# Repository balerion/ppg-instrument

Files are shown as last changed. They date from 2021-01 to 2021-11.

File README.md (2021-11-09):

# ppg-instrument
This is an instrument meant for assisting in the monitoring of combustion engines in powered paragliding.

The main features are an RPM gauge, temperature sensors, and hour meter.

There are plans for including and logging other sensors, such as accelerometers, barometer, temperature/humidity.

There are also plans for including a customizable maintenance schedule.

## Electronics
This is based on the [Adalogger](https://www.adafruit.com/?q=adalogger&sort=BestMatch) (trying to support both 32u4 and M0), because of the nice format and space savings from having battery management and SD on the board.

The display is a 0.91" OLED, the choice is mainly due to what I had lying around. A nice drop-in alternative can be a 0.96" OLED, this will probably come in the future.

RPM readings are performed by capacitive coupling a pigtail wire to the spark plug cable. There is a board I designed with input protection for the uController pins.

I wanted to avoid hard switches due to vibrations, in case the instrument gets mounted on the swing arms, so I ended up using all software-based power management and steel tactile domes.

Temperature readings are performed with K-type thermocouples and an AD8495 based amplifier, such as the relatively cheap CJMCU 8495 boards

### Note on thermocouple sensor
The thermocouple CHT (cylinder head temperature) sensor is kind of tricky. This is an insulated thermocouple connected to a spark plug gasket.

The sensors you can find online are really expensive or do not work well. Since electrical insulation is needed due to large voltage oscillations of the engine block, commercial cheaper sensors tend to use ceramics just dropped in a steel tube, and have a huge air gap between the thermocouple junction and the spark plug gasket. Furthermore, the gaskets are usually made of steel. This makes the response extremely slow: dipped in boiling water, it takes 10 minutes to get 95°C.

A CHT sensor can easily be built using an M12 eye cable lug, which needs to be adapted to remove the tinning, smooth out the surface, and make the hole 14.2mm.

After adapting the gasket, the thermocouple junction can be insulated using a wrap of kapton tape (max T>300C), then tightly wrapping in aluminum foil, and then carefully crimping the thermocouple junction in the eye terminal.

## Case
For the case, there are 2 parts plus the buttons that can be 3d printed with an FDM printer.

I printed all parts in PLA with 0.2mm layers, the lid and box with supports. For printing the buttons, make sure the first layer height is just right.

Inspiration for the buttons came from [here](https://www.instagram.com/p/BypbXyjohMr/)

I also use a 1" dual hook & loop strap (like velcro omni-tape) to keep it fixed to my throttle.

## Assembly Instructions
Check [here](hardware/Assembly%20Instructions/Instructions.md) for assembly instructions.

### Parts List 
|Part|Source|Price| 
| --- |:---:| -----:|
| Adalogger board | [Adafruit](https://www.adafruit.com/product/2796), [Amazon](https://www.amazon.de/Adafruit-Feather-M0-Adalogger-ADA2796/dp/B01BMRDBXW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) | €27.90 |
| Battery | [1300mAh 503759](https://www.ebay.com/itm/171260143191) | €6.60 |
| SD card | [ebay, 4Gb](https://www.ebay.it/itm/303426113204?ssPageName=STRK%3AMEBIDX%3AIT&_trksid=p2060353.m2749.l2649) | €7.16 |
| Thermocouple amp | [Aliexpress](https://www.aliexpress.com/i/33014907258.html) | $5.38 |
| Thermocouple wire | [ebay](https://www.ebay.it/itm/274905710453?hash=item4001a83f75:g:jTAAAOSwh59hFzC6) | €2.48 per meter |
| Spark plug gasket | [Amazon](https://www.ebay.it/itm/272789432218?hash=item3f8384679a:g:DPAAAOSwQcJaDBZB) | ~ €2.00 per piece |
| 3D printed parts | filament | ~ €1.00 |
| Spark plug input board | | ~ €3.00 |
| Screen | [0.91" white oled, Amazon](https://www.amazon.de/-/en/0-91-I2-°C-Serial-128x32-White-Display-Arduino/dp/B06XFHGT9P/ref=sr_1_3?keywords=0%2C91+weiß+oled&qid=1636468399&qsid=262-1393502-5513624&sr=8-3&sres=B07V8B3LSR%2CB07TKPXFLV%2CB06XFHGT9P%2CB0979YQWGT%2CB08K8XVJBT%2CB07TWJR7L9%2CB07JN2NHT4%2CB079KRC9X3%2CB01IROOJ48%2CB08216LXVQ%2CB01N97V0KH%2CB07FYG8MZN%2CB074N9VLZX%2CB014I8SIJY%2CB07PGZ9B51%2CB08MZV1TT9) | €3.00 per piece |
| hook&loop strap | [treadlite](https://www.treadlitegear.co.uk/ripfast-solo-hook-and-loop-in-20mm-and-25mm-hiking-bike-packing-choose-length-211-p.asp)  | £5.99 |
| Tactile dome switches | [Aliexpress](https://www.aliexpress.com/item/32668884101.html) | $0.24 for 2 pieces |

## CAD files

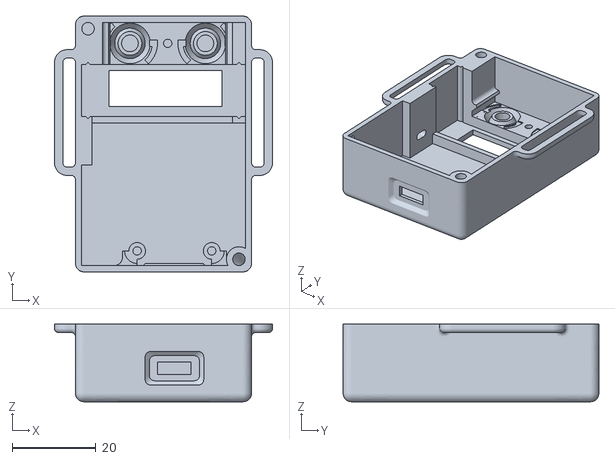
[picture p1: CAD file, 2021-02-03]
hardware/ppg-instrument box_v1.0.stl
52.0 x 61.0 x 18.5

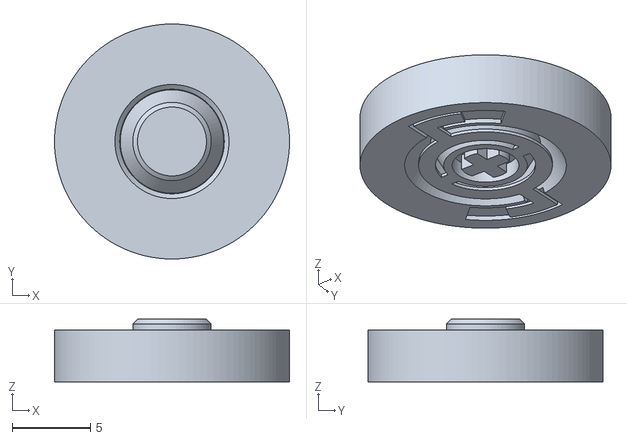
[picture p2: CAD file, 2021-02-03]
hardware/button_small.stl
15.0 x 15.0 x 4.00

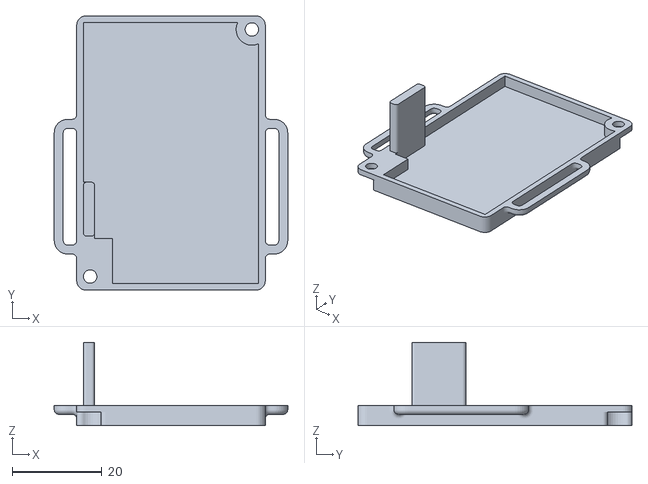
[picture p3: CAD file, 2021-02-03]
hardware/lid_v1.0.stl
52.0 x 61.0 x 18.5

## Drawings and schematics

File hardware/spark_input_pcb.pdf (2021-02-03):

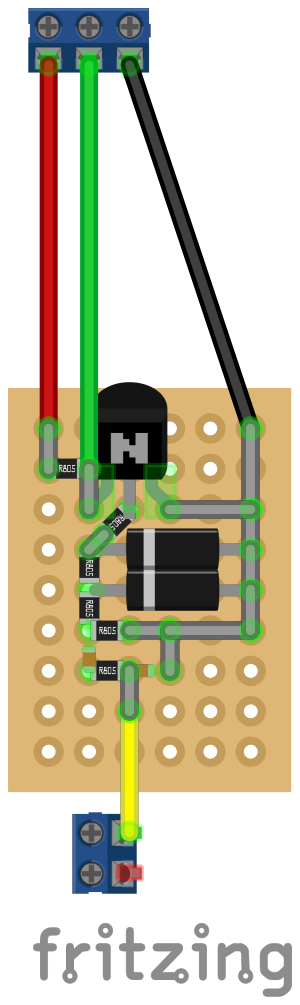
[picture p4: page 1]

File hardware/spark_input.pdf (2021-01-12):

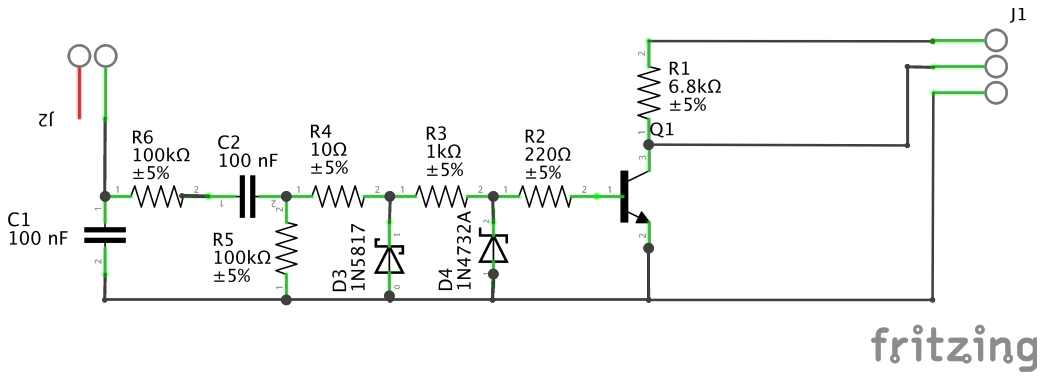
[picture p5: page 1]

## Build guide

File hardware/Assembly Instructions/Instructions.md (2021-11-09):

# Assembly

To start the assembly, you will most likely need:

- The instrument case
- The main board (Feather M0/32u)
- Buttons board
- Thermocouple board
- Spark plug sensor board
- Battery
- Screen

There really isn't so much space in the case, so I made these instructions to show how I assembled the instrument.

# Buttons
For the buttons, I chose to go for a cheaper, more reliable, more customizable way. This is however a little more tricky.
You need some of [these](https://www.aliexpress.com/item/32668884101.html).

You can use 2x steel tactile dome switches (triangular 6mm, 2 leg such as ), and a pcb. A piece of perfboard should also work.

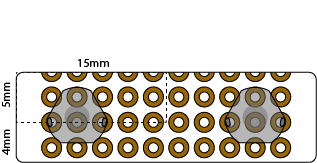
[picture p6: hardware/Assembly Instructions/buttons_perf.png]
image of perf buttons


The board size is 30mm x 9mm, with buttons distanced 18mm and centered on the board. If you are using perfboard, the switch leg holes will not be centered vertically, but will be 5mm/4mm away from the top and bottom edge.

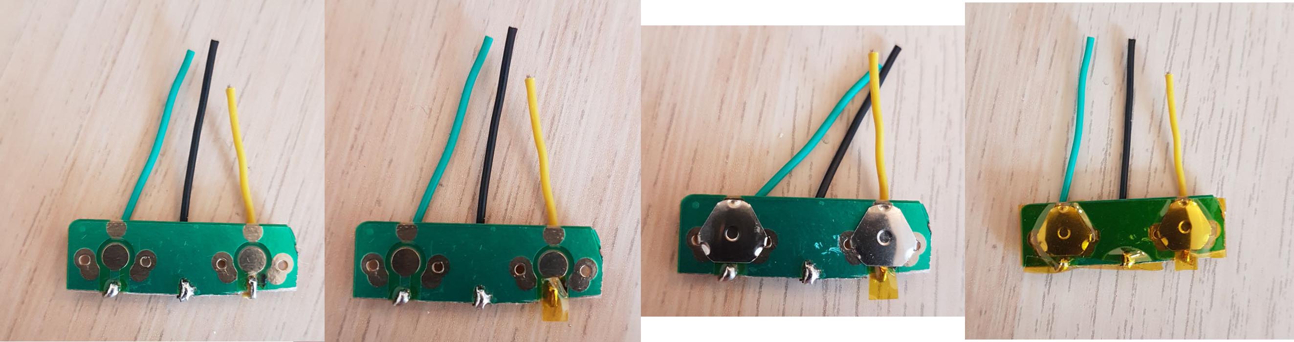
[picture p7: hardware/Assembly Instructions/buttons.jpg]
button assembly


Isolate the connections coming from the central pad with PCB enamel or a little bit of kapton tape, otherwise the buttons will be shorted all the time.

Connect very thin wires to close-by pads, use very little solder so the connection is as thin as possible and fits under the button. Use a solder wick to help out getting a thin layer.
Then, from such near-by pads, get thicker wires to go to the back of the board.

The dome switch feet need to be grounded, while the central pad goes to the input pin.

Covering the buttons with tape helps keep them in place.

In the end, you get one wire per button plus the ground.

# Spark plug sensor
The spark plug input circuit works by capacitive coupling a pigtail wire to the spark plug cable. The spark plug cable itself will reach pretty high negative voltages, in the 10kV range. This in turn causes a positive voltage spike in the pigtail wire. The circuit is designed with an input low pass filter, so the spike does not reach dangerous values, and right after this, a high pass filter that is more meant as a protection than a filter. Then, there are two diodes for input protection against overvoltages and undervoltages for a transistor, which generates a ~20us low-logic pulse every time a spark happens.

In general, 5-6 wraps should be sufficient. Use the smallest number of wraps that will give a consistent reading. Too many wraps can cause issues with ignition and may damage the board.

spark plug sensor schematic

You can make the circuit on perf board, using smd components.

Remember to wrap the whole sensor in isolating tape, it is probably not a good idea to have shorts with other parts of the instrument.

# Fitting all the parts

Start by placing the 3d printed butting in their niches. Then, insert the button board in the retaining shelf. this is a pretty tight fit, so be patient and get it to align well.

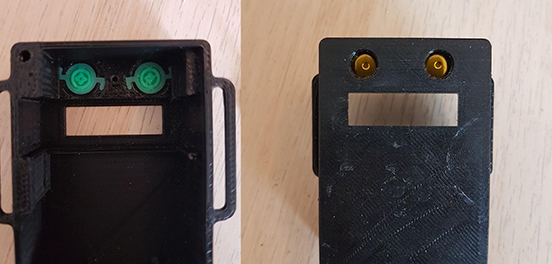
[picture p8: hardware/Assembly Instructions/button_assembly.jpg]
fitting buttons


The screen is small and quite delicate. Be careful when assembling. Should probably design a better retaining niche.

The micro SD card quality is quite important. When not in use, larger, faster SD cards will use up a lot of battery. Try to find cheap, slow ones. [These](https://www.ebay.it/itm/303426113204?ssPageName=STRK%3AMEBIDX%3AIT&_trksid=p2060353.m2749.l2649) 4Gb cards use 200uA when in standby.

Isolate the SD card slot with some tape. This can cause shorts with the underlying boards.

After this, try fitting the feather board. This will give you a good idea of where the connection wires should be. Try to keep this arrangement while soldering all the connections.

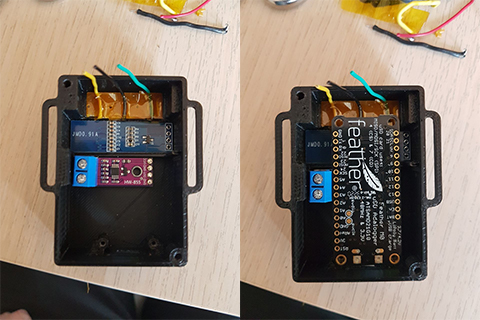
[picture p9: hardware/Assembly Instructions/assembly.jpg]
fitting feather


The battery I had lying around was a 1000mAh 60x40mmx5mm battery (504060 battery format). This was pretty old, now you can either find the same capacity with a smaller size, or up to 1800mAh for the same format. Probably a smaller battery will fit nicely.

The fastening strap is mixed hook&loop, which means it sticks to itself. I found this pretty convenient, and pretty safe.

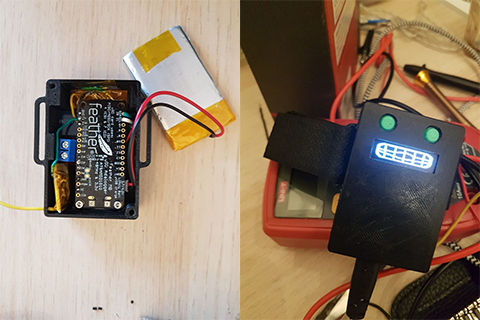
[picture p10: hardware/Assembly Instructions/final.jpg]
functioning


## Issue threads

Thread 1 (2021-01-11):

RPM meter

balerion, 2021-01-11:
The instrument needs an RPM meter

<!-- Edit the body of your new issue then click the ✓ "Create Issue" button in the top right of the editor. The first line will be the issue title. Assignees and Labels follow after a blank line. Leave an empty line before beginning the body of the issue. -->

Closed 2021-01-11.

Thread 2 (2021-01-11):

Logger

balerion, 2021-01-11:
The instrument needs to log data, most importantly operational hours.
This needs to be associated to some type of output, e.g. per flight and per service interval.

<!-- Edit the body of your new issue then click the ✓ "Create Issue" button in the top right of the editor. The first line will be the issue title. Assignees and Labels follow after a blank line. Leave an empty line before beginning the body of the issue. -->

balerion, 2021-01-12:
this can store all the info to the sd card every time interval in a dedicated folder structure

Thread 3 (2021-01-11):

Output display

balerion, 2021-01-11:
The instrument needs a meaningful output display. This can be a 0.91" OLED or a 0.96" OLED based on the SSD1306 chip.

<!-- Edit the body of your new issue then click the ✓ "Create Issue" button in the top right of the editor. The first line will be the issue title. Assignees and Labels follow after a blank line. Leave an empty line before beginning the body of the issue. -->

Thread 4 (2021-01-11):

CHT gauge

balerion, 2021-01-11:
The instrument needs thermocouple temperature readings for the CHT (and possibly for the EGT).

<!-- Edit the body of your new issue then click the ✓ "Create Issue" button in the top right of the editor. The first line will be the issue title. Assignees and Labels follow after a blank line. Leave an empty line before beginning the body of the issue. -->

Closed 2021-02-09.

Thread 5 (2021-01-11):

Sensor logging

balerion, 2021-01-11:
The instrument could log various sensors, like temperature/humidity, barometer/altimeter, accelerometers.

<!-- Edit the body of your new issue then click the ✓ "Create Issue" button in the top right of the editor. The first line will be the issue title. Assignees and Labels follow after a blank line. Leave an empty line before beginning the body of the issue. -->

balerion, 2021-01-12:
Also battery management

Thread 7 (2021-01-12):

Sleep-wakeup

balerion, 2021-01-12:
Needs a convenient software sleep/wakeup system, so no hardware battery switch is necessary.
It could use something like an interrupt (there should be one interrupt pin still free) or a check every second or so:
```
LowPower.deepSleep(milliseconds);
```

<!-- Edit the body of your new issue then click the ✓ "Create Issue" button in the top right of the editor. The first line will be the issue title. Assignees and Labels follow after a blank line. Leave an empty line before beginning the body of the issue. -->

Closed 2021-01-14.

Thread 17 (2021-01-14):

Optimize code
Assignees: @balerion
Labels: enhancement

balerion, 2021-01-14:
Needs code optimization for reducing flash space as much as possible.
Need to move the sleep/wakeup outside the loop

<!-- Edit the body of your new issue then click the ✓ "Create Issue" button in the top right of the editor. The first line will be the issue title. Assignees and Labels follow after a blank line. Leave an empty line before beginning the body of the issue. -->

balerion, 2021-02-09:
workaround is to use board with more flash. Will be moving to Adalogger M0 anyway

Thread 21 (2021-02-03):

instrument uses power even in off mode

balerion, 2021-02-03:
because sensors are connected directly to power pins, they are powered even in off state.
Possible solution is to use a digital pin to power the sensors

<!-- Edit the body of your new issue then click the ✓ "Create Issue" button in the top right of the editor. The first line will be the issue title. Assignees and Labels follow after a blank line. Leave an empty line before beginning the body of the issue. -->

balerion, 2021-02-03:
fixed in #20

Closed 2021-02-03.

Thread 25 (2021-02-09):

power usage goes up after 1s of sleep

balerion, 2021-02-09:
fixed in M0 version. In the 32u4 version, after the first sleep cycle, the board is not put back in deep sleep mode again

balerion, 2021-03-14:
fixed by 02334bd079bea62a9c9fc354ac782ae14e71a053

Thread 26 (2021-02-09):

slow rpm inaccurate

balerion, 2021-02-09:
with the current method of counting spark firings between intervals, at low rpms, the reading is inaccurate due to a variable number of firings in a check cycle (~2 in 60ms at 2000rpm), so the error becomes 1000rpm at 2000rpm

A solution is to measure time between firings instead

balerion, 2021-03-14:
fixed by 55c965e9009cd1c129962a9e6e5bf15ba3e67741

Closed 2021-03-14.

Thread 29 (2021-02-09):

wakeup slow

balerion, 2021-02-09:
the current wakeup method is super silly, considering the button pin is on an interrupt in either board. Should change to a faster interrupt based wakeup, also allowing for less battery usage when sleeping

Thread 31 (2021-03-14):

documentation needed

balerion, 2021-03-14:
needs documentation on construction, assembly, and usage

balerion, 2021-11-09:
missing assembly instructions fixed by #35

balerion, 2021-11-09:
construction info fixed by 11948a12fe45318902e3622fe65ae1f319eafc91

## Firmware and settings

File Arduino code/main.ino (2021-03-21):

#include <SPI.h>
#include <U8g2lib.h>
#include <Wire.h>

#include "ArduinoLowPower.h"
#include "SD.h"
#include "src/graphics.h"

// Pin definition
#define VBATPIN A7
#define CHTMEASUREPIN A1
#define RPMPIN 1
#define BUTTONPIN 0
#define RPMPOWER A2
#define CHTPOWER A3

#define chipSelect 4

// uncomment this for dev mode
// #define DEVMODE 1
// #define FAKERPM 1

// SAMD serial port adaptation
#if defined(ARDUINO_SAMD_ZERO) && defined(SERIAL_PORT_USBVIRTUAL)
// Required for Serial on Zero based boards
#define Serial SERIAL_PORT_USBVIRTUAL
#endif

// Battery monitoring
const float minVoltage = 3.2;
const float maxVoltage = 4.1;
const float refVoltage = 3.3;

// defines for tacho
const float min_rpm = 2000;
const float max_rpm = 8000;

float rpm_filt = 0;
float ww = 3;  // filter weight. larger numbers -> slower filters. 40 is ..s, 1
               // is no filtering

// defines for tacho: Timer auxiliary variables
unsigned long tt = millis();
unsigned long dt = micros();
volatile unsigned long t0 = micros();
volatile unsigned long t1 = micros();
// volatile unsigned long oldtime = micros();
volatile float rev = 0;
float rpm = 0;

unsigned long fakerpm_dt = 0;
unsigned long fakerpm_tt = 0;

unsigned long lastTrigger = 0;
boolean startTimer = false;

// Defining variables for OLED display
char displayBuffer[20];
String displayString;
unsigned long lastSignalBlink;
unsigned long lastDataRotation;

float batteryVoltage = 0;
float throttle = 0;

bool wasSleeping = true;
bool awake = true;
float sleepInput = 0;

// Defining the type of display used (128x32)
U8G2_SSD1306_128X32_UNIVISION_F_HW_I2C u8g2(U8G2_R0, U8X8_PIN_NONE);

// time keeping variables
long tt_loop = 0;
long loopUpdateTime = 25;
long tt_button = 0;
long dt_button = 500;
long tt_slowdraw = 0;
long dt_slowdraw = 1000;

unsigned long tt_running = 0;
unsigned long current_runtime = 0;
unsigned long total_runtime = 0;

// SD card stuff
File logfile;

// blink out an error code
void error(uint8_t errno) {
  while (1) {
    uint8_t i;
    for (i = 0; i < errno; i++) {
      digitalWrite(LED_BUILTIN, HIGH);
      delay(100);
      digitalWrite(LED_BUILTIN, LOW);
      delay(100);
    }
    for (i = errno; i < 10; i++) {
      delay(200);
    }
  }
}

// sleepy function
void prepareSleep() {
  u8g2.setPowerSave(1);
  pinMode(RPMPOWER, INPUT);
  pinMode(CHTPOWER, INPUT);
  pinMode(13, INPUT);
  digitalWrite(RPMPOWER, LOW);
  digitalWrite(CHTPOWER, LOW);
  wasSleeping = false;
  logfile.println(total_runtime);
  logfile.flush();
  logfile.close();
  LowPower.deepSleep(1000);
}

// wakeup function
void wakeupProc() {
  u8g2.setPowerSave(0);

  u8g2.clearBuffer();
  u8g2.drawXBMP(0, 0, mouth1_width, mouth1_height, mouth1_bits);
  u8g2.sendBuffer();
  delay(2000);
  u8g2.clearBuffer();

#if defined(FAKERPM)
  pinMode(RPMPOWER, INPUT);
  digitalWrite(RPMPOWER, LOW);
#else
  pinMode(RPMPOWER, OUTPUT);
  digitalWrite(RPMPOWER, HIGH);
#endif
  pinMode(CHTPOWER, OUTPUT);
  pinMode(LED_BUILTIN, OUTPUT);
  digitalWrite(CHTPOWER, HIGH);

  char filename[17];
  strcpy(filename, "logger/HOURS.TXT");
  // for (uint8_t i = 0; i < 100; i++) {
  //   filename[10] = '0' + i / 10;
  //   filename[11] = '0' + i % 10;
  //   // create if does not exist, do not open existing, write, sync after
  //   write if (!SD.exists(filename)) {
  //     break;
  //   }
  // }
  logfile = SD.open(filename, FILE_READ);
  if (!logfile) {
#if defined(DEVMODE)
    Serial.print("Couldnt open ");
    Serial.println(filename);
#endif
    error(2);
  }

  while (logfile.available()) {
    unsigned long runtime_temp = logfile.parseInt();
    if (runtime_temp > 0) {
      total_runtime = runtime_temp;
    }
  }
#if defined(DEVMODE)
  Serial.println(total_runtime);
#endif
  logfile.close();

  logfile = SD.open(filename, FILE_WRITE);
  logfile.seek(EOF);
  if (!logfile) {
#if defined(DEVMODE)
    Serial.print("Couldnt open for write ");
    Serial.println(filename);
#endif
    error(3);
  }

  // total_runtime = EEPROMReadlong(0);
}

void setup() {
  pinMode(RPMPIN, INPUT_PULLUP);
  attachInterrupt(digitalPinToInterrupt(RPMPIN), rpm_isr, FALLING);

  pinMode(BUTTONPIN, INPUT_PULLUP);

  // initialize serial:
#if defined(DEVMODE)
  Serial.begin(115200);
  while (!Serial) delay(10);  // wait for native usb
  Serial.println("Devmode ON");
#endif

  u8g2.setBusClock(400000);
  u8g2.begin();

  if (!SD.begin(chipSelect)) {
#if defined(DEVMODE)
    Serial.println("SD init failed");
#endif
  }
  wakeupProc();
}

void loop() {
  // check sleep status
  if (digitalRead(BUTTONPIN) == LOW) {
    bool switchSleepState = true;
    // stop everything for 1s while checking button is still down
    tt_button = millis();
    do {
      if (digitalRead(BUTTONPIN) == HIGH) switchSleepState = false;
    } while (millis() - tt_button < dt_button);

    // if after 1 second button is still down, switch sleep state
    if (switchSleepState) {
      if (awake) {
        prepareSleep();
        awake = false;
      } else {
        wakeupProc();
        awake = true;
      }
    }
  }

  // waking code
  if (awake) {
#if defined(DEVMODE)
    while (Serial.available() > 0) {
      // look for the next valid integer in the incoming serial stream:
      rev = Serial.parseInt();
#if defined(FAKERPM)
      fakerpm_dt = 60000.0 / rev;
#endif
      if (Serial.read() == '\n') {
        Serial.println(rev);
        if (rev < 0) {
          total_runtime = -rev;
          Serial.print("resetting total_runtime: ");
          Serial.println(total_runtime);
        }
      }
    }

#if defined(FAKERPM)
    if (millis() - fakerpm_tt > fakerpm_dt) {
      // pinmode input detaches internal pullup, so transistor in pcb takes pin
      // to 0V however, it also detaches the interrupt for some reason
      pinMode(RPMPIN, INPUT);
      delayMicroseconds(20);
      pinMode(RPMPIN, INPUT_PULLUP);
      attachInterrupt(digitalPinToInterrupt(RPMPIN), rpm_isr, FALLING);
      fakerpm_tt = millis();
    }
#endif

    // Serial.println(rpm_filt);
#endif
    if (millis() - tt_loop > loopUpdateTime) {
      updateRunningTime();
      updateTacho();
#if !defined(FAKERPM)
      readBatteryVoltage();
      readCht();
      updateMainDisplay();
#endif
      tt_loop = millis();
    }
  } else {
    prepareSleep();
    awake = false;
  }
}

void updateRunningTime() {
  if (rpm_filt > min_rpm) {
    unsigned int dt = millis() - tt_running;
    tt_running = millis();
    current_runtime += dt;
    total_runtime += dt;
  } else {
    current_runtime = 0;
    tt_running = millis();
  }
}

void displayTime() {
  // int x = 89;
  // int y = 22;
  int x = 104;
  int y = 22;
  char buffer[10];  // make this big enough to hold the resulting string
  snprintf(
      buffer, sizeof(buffer), "%02d:%02d:%02d",
      int(current_runtime / 3600000.0),
      int(current_runtime / 60000.0) - int(current_runtime / 3600000.0) * 60,
      int(current_runtime / 1000.0) - int(current_runtime / 60000.0) * 60);

  u8g2.setFont(u8g2_font_profont10_mn);
  u8g2.drawStr(x, y, buffer);

  snprintf(buffer, sizeof(buffer), "%02d:%02d:%02d",
           int(total_runtime / 3600000.0),
           int(total_runtime / 60000.0) - int(total_runtime / 3600000.0) * 60,
           int(total_runtime / 1000.0) - int(total_runtime / 60000.0) * 60);

  u8g2.setFont(u8g2_font_profont10_mn);
  u8g2.drawStr(x, y + 8, buffer);

  // Serial.print("total runtime: ");
  // Serial.println(total_runtime);
  // buffer[10];  // make this big enough to hold the resulting string
  // snprintf(buffer, sizeof(buffer), "%02d:%02d:%02d",
  //          int(total_runtime / 3600000.0),
  //          int(total_runtime / 60000.0) - int(total_runtime / 3600000.0) *
  //          60, int(total_runtime / 1000.0) - int(total_runtime / 60000.0) *
  //          60);
  // Serial.println(buffer);

  // time to OLED
  // displayString = "";
  // for (int i = 0; i < pp.decimals; i++) {
  //   if (last < pow(10, i)) {
  //     displayString = "0" + displayString;
  //   } else {
  //     displayString = (String)last;
  //   }
  // }
  // // displayString = "." + displayString;
}

// Function to calculate and return the thermocouple reading.
float readChtVoltage() {
  float chtVoltage = 0.0;
  int total = 0;
  int extrabits = 2;

  int nn = pow(2, 2 * extrabits);
  for (int i = 0; i < 16; i++) {
    total += analogRead(CHTMEASUREPIN);
  }

  chtVoltage = (refVoltage / 1024.0) * ((float)total / 16.0);

  return chtVoltage;
}

// function for calibrating cht voltage to temperature in °C
float calibratedCht(float voltage) { return (voltage - 1.25) / 0.005; }

float chtReading = 0;
void readCht() {
  float chtVoltage = readChtVoltage();
  chtReading = calibratedCht(chtVoltage);
#if defined(DEVMODE)
  Serial.print("CHT: ");
  Serial.println(chtReading);
#endif
}

void readBatteryVoltage() {
  batteryVoltage = analogRead(VBATPIN);
  batteryVoltage *= 2;           // we divided by 2, so multiply back
  batteryVoltage *= refVoltage;  // Multiply by 3.3V, our reference voltage
  batteryVoltage /= 1024.0;      // convert to voltage

#if defined(DEVMODE)
  Serial.print("VBat: ");
  Serial.println(batteryVoltage);
#endif
}

void rpm_isr() {
  t1 = micros();
  rev++;
}

void updateTacho() {
  if (rev > 0) {
    dt = t1 - t0;
    if (dt > 0) {
      rpm = (rev / dt) * 60000000;
      t0 = t1;
#if defined(FAKERPM)
      rev = 0;
#endif
#if !defined(DEVMODE)
      rev = 0;
#endif
    }
    rpm_filt =
        constrain((1 / ww) * (rpm) + (1 - (1 / ww)) * rpm_filt, 0, max_rpm);
#if defined(DEVMODE)
    Serial.print("rpm: ");
    Serial.print(rpm_filt);
    Serial.print(" ");
    Serial.println(dt);
#endif
  }
}

typedef struct printStruct {
  float value;
  String suffix;
  String prefix;
  int decimals;
  int bigChars;
  int x;
  int y;
} printStruct;

typedef struct barStruct {
  float value;
  float max;
  float min;
  int x;
  int y;
} barStruct;

void updateMainDisplay() {
  // u8g2.clearBuffer();

  barStruct rpmBar;
  rpmBar.value = rpm_filt / 1000;
  rpmBar.x = 0;
  rpmBar.y = 18;
  rpmBar.max = max_rpm / 1000;
  rpmBar.min = min_rpm / 1000;

  barStruct chtBar;
  chtBar.value = chtReading;
  chtBar.x = 0;
  chtBar.y = 0;
  chtBar.max = 205;
  chtBar.min = 0;

  printStruct rpmPrint;
  rpmPrint.value = rpm_filt / 1000;
  rpmPrint.suffix = "krpm";
  rpmPrint.prefix = "REVS";
  rpmPrint.decimals = 1;
  rpmPrint.bigChars = 1;
  rpmPrint.x = 0;
  rpmPrint.y = 16;

  printStruct chtPrint;
  chtPrint.value = chtReading;
  chtPrint.suffix = "\xB0";
  chtPrint.suffix += "C";
  chtPrint.prefix = "CHT";
  chtPrint.decimals = 0;
  chtPrint.bigChars = 3;
  chtPrint.x = 0;
  chtPrint.y = 0;

  // u8g2.firstPage();
  // do {
  smallPrint(rpmPrint);
  drawBar(chtBar);
  drawBar(rpmBar);
  // if (millis() - tt_slowdraw > dt_slowdraw) {
  // tt_slowdraw = millis();
  smallPrint(chtPrint);
  displayTime();
  drawBatteryLevel();
  u8g2.sendBuffer();
  // }
  // } while (u8g2.nextPage());
}

// void bigPrint(struct printStruct pp)
// {
//   int first, last;

//   // Display prefix (title)
//   displayString = pp.prefix;
//   displayString.toCharArray(displayBuffer, 10);
//   u8g2.setFont(u8g2_font_profont12_tr);
//   u8g2.drawStr(pp.x, pp.y - 1, displayBuffer);

//   // Split up the float value: a number, b decimals.
//   first = abs(floor(pp.value));
//   last = pp.value * pow(10, 2) - first * pow(10, 2);

//   // Add leading zeros (2+bigChars-decimals)
//   if (first < pow(10, 2) && pp.bigChars > 2)
//   {
//     displayString = "0" + (String)first;
//   }
//   else
//   {
//     if (first <= 9 && pp.bigChars > 1)
//     {
//       displayString = "00" + (String)first;
//     }
//     else
//     {
//       displayString = (String)first;
//     }
//   }

//   // Display numbers
//   displayString.toCharArray(displayBuffer, 10);
//   u8g2.setFont(u8g2_font_logisoso22_tn);
//   u8g2.drawStr(pp.x + 55, pp.y + 13, displayBuffer);

//   // Display decimals
//   displayString = ".";

//   if (pp.decimals > 1)
//   {
//     if (last <= 9)
//     {
//       displayString += "0" + (String)last;
//     }
//     else
//     {
//       displayString += (String)last;
//     }
//   }
//   else
//     displayString += (String)last;

//   displayString.toCharArray(displayBuffer, pp.decimals + 2);
//   u8g2.setFont(u8g2_font_profont12_tr);
//   u8g2.drawStr(pp.x + 86, pp.y - 1, displayBuffer);

//   // Display suffix
//   displayString = pp.suffix;
//   displayString.toCharArray(displayBuffer, 10);
//   u8g2.setFont(u8g2_font_profont12_tr);
//   u8g2.drawStr(pp.x + 86 + 2, pp.y + 13, displayBuffer);
// }

void smallPrint(struct printStruct pp) {
  int first, last;

  // Split up the float value: a number, b decimals.
  first = abs(floor(pp.value));
  last = abs(
      floor(pp.value * pow(10, pp.decimals) - first * pow(10, pp.decimals)));

  // Add leading zeros (2+bigChars-decimals)
  displayString = "";
  for (int i = 0; i < pp.bigChars; i++) {
    if (first < pow(10, i)) {
      displayString = "0" + displayString;
    } else {
      displayString = (String)first;
    }
  }

  // Display numbers
  displayString.toCharArray(displayBuffer, 10);
  u8g2.setFont(u8g2_font_10x20_tn);
  u8g2.drawStr(pp.x + 55, pp.y + 13, displayBuffer);

  // Display decimal point
  if (pp.decimals > 0) {
    displayString = ".";
    displayString.toCharArray(displayBuffer, 10);
    u8g2.setFont(u8g2_font_10x20_tn);
    u8g2.drawStr(pp.x + 55 + 10 * (pp.bigChars) - 3, pp.y + 13, displayBuffer);
  }

  // Display decimals
  displayString = "";
  for (int i = 0; i < pp.decimals; i++) {
    if (last < pow(10, i)) {
      displayString = "0" + displayString;
    } else {
      displayString = (String)last;
    }
  }
  // displayString = "." + displayString;

  displayString.toCharArray(displayBuffer, pp.decimals + 2);
  u8g2.setFont(u8g2_font_10x20_tn);
  u8g2.drawStr(pp.x + 55 + 10 * (pp.bigChars) - 3 + 8, pp.y + 13,
               displayBuffer);

  // Display suffix
  displayString = pp.suffix;
  if (displayString.length() < 3) {
    displayString.toCharArray(displayBuffer, 10);
    u8g2.setFont(u8g2_font_profont12_mf);
    u8g2.drawStr(pp.x + 55 + 10 * (pp.bigChars + pp.decimals) - 3 +
                     (pp.decimals > 0 ? 8 : 2) + 2,
                 pp.y + 13, displayBuffer);
  } else {
    displayString.substring(0, 2).toCharArray(displayBuffer, 10);
    u8g2.setFont(u8g2_font_profont10_tr);
    u8g2.drawStr(pp.x + 55 + 10 * (pp.bigChars + pp.decimals) - 3 +
                     (pp.decimals > 0 ? 8 : 2) + 2,
                 pp.y + 13 - 6, displayBuffer);

    displayString.substring(2).toCharArray(displayBuffer, 10);
    u8g2.setFont(u8g2_font_profont10_tr);
    u8g2.drawStr(pp.x + 55 + 10 * (pp.bigChars + pp.decimals) - 3 +
                     (pp.decimals > 0 ? 8 : 2) + 2,
                 pp.y + 13, displayBuffer);
  }
}

// Function used to indicate the remotes battery level.
void drawBatteryLevel() {
  int level = constrain(
      (batteryVoltage - minVoltage) * 100 / (maxVoltage - minVoltage), 0, 100);

  // Position on OLED
  int x = 108;
  int y = 0;

  u8g2.drawFrame(x + 2, y, 18, 9);
  u8g2.drawBox(x, y + 2, 2, 5);

  u8g2.setDrawColor(0);
  u8g2.drawBox(x + 3, y + 1, 16, 7);
  u8g2.setDrawColor(1);

  for (int i = 0; i < 5; i++) {
    int p = round((100 / 5) * i);
    if (p < level) {
      u8g2.drawBox(x + 4 + (3 * i), y + 2, 2, 5);
    }
  }
}

void drawBar(
    struct barStruct pp)  // Draws Battery Level when not being used as Throttle
{
  u8g2.setDrawColor(0);
  u8g2.drawBox(pp.x + 1, pp.y + 1, 50, 8);
  u8g2.setDrawColor(1);
  u8g2.drawHLine(pp.x, pp.y, 52);
  u8g2.drawVLine(pp.x, pp.y, 10);
  u8g2.drawVLine(pp.x + 52, pp.y, 10);
  u8g2.drawHLine(pp.x, pp.y + 10, 5);
  u8g2.drawHLine(pp.x + 52 - 4, pp.y + 10, 5);

  int width = constrain(map_float(pp.value, pp.min, pp.max, 0, 49), 0, 49);
  for (int i = 0; i < width; i++) {
    u8g2.drawVLine(pp.x + i + 2, pp.y + 2, 7);
  }

  // if (throttle >= 127)
  // {
  //   int width = map(inputValue, 127, 255, 0, 49);

  //   for (int i = 0; i < width; i++)
  //   {
  //     //if( (i % 2) == 0){
  //     u8g2.drawVLine(x + i + 2, y + 2, 7);
  //     //}
  //   }
  // }
  // else
  // {
  //   int width = map(inputValue, 0, 126, 49, 0);
  //   for (int i = 0; i < width; i++)
  //   {
  //     //if( (i % 2) == 0){
  //     u8g2.drawVLine(x + 50 - i, y + 2, 7);
  //     //}
  //   }
  // }
}

float map_float(float x, float in_min, float in_max, float out_min,
                float out_max) {
  return (x - in_min) * (out_max - out_min) / (in_max - in_min) + out_min;
}

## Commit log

2021-01-11 initial arduino sketch
2021-01-11 add rpm reading on pin 0
2021-01-11 add filtered display reading for rpms
2021-01-12 add capacitive spark input schematic
    [connections.fzz]
2021-01-12 Sensor logging improves #5
2021-01-13 Output display improves printing #3
2021-01-14 Sleep-wakeup first fix #7
    [main.ino]
2021-01-18 first box test and spark input documentation
    [ppg-instrument box.stl]
2021-01-24 correctly display bars and battery
    [main.ino]
2021-01-24 new box version
    [ppg-instrument box.stl, ppg-instrument_box_v0.4.stl]
2021-02-03 final box version
    [button_small.stl, lid_v1.0.stl, ppg-instrument box_v1.0.stl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]
2021-02-03 fix power consumption when off
    [main.ino]
2021-03-18 fixes rpm reader bug
    [main.ino]
2021-11-09 added buttons instructions
2021-11-09 add link to assembly instructions in Readme
2021-11-09 add spark plug sensor info
